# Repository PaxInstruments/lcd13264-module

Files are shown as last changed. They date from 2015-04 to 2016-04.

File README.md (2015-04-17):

# Pax Instruments
# LCD13264-module

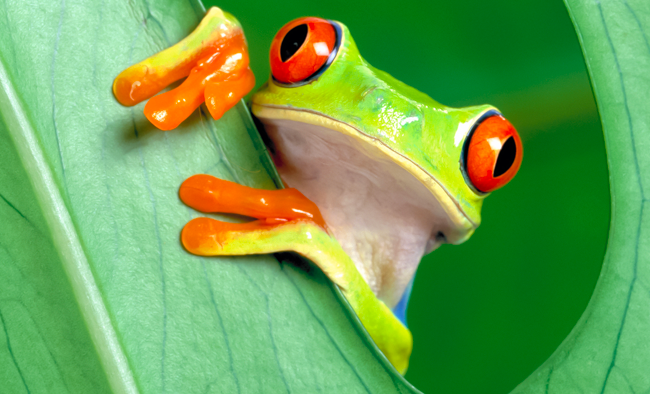
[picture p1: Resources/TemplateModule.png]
  
[Pax Instruments Template Module](<link to store page>)

## Overview
The Pax Instruments LCD13264-module is a breakout shield for the LCD23164 graphic LCD.

## Repository Contents
- __Datasheets__ - Datasheets for relevant components and parts
- __Electronics__ - All PCB and schematic design files
- __Enclosure__ - Enclosure 3D design files
- __Firmware__ - Firmware, libraries, and examples
- __Production__ - Manufacturing resources
- __Resources__ - Other resources

## Product Versions

## License Information
```
Place the license statement here
```

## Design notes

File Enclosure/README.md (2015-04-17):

# Pax Instruments
# LCD12364-shield Enclosure

Developed by <person(s) name> for [Pax Instruments](http://paxinstruments.com/), an original design.

## Overview
This is the enclsoure for the Pax Instruments LCD13264-module designed in <software package>. STL files are included for your convenience.

## License
```
Place the license statement here
```

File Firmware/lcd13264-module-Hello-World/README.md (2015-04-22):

# Pax Instruments
# LCD12364-shield Firmware

Developed by <person(s) name> for [Pax Instruments](http://paxinstruments.com/) based on Arduino and other Open Source libraries.

## Overview
There is no firmware required for the Pax Instruments LCD12364-shield.

## Required libraries
- Link to a forked Pax Instruments version
- of any  libraries used

## Installation
1. Copy libraryName into your <Arduino folder>/libraries/
2. Restart the ARduino IDE

## Example 1 - Hello, world!
```
void setup() {
    // The setup function. This runs once.
}

void loop() {
    // The loop function. This restarts when complete.
}
```

## History
__v0.2: 2015-02-22 by Charles Edward Pax__

- Major change 1
- Major change 2

__v0.1: 2015-02-20 by Charles Edward Pax__

- Major change 1
- Major change 2

## License
```
Place the license statement here
```

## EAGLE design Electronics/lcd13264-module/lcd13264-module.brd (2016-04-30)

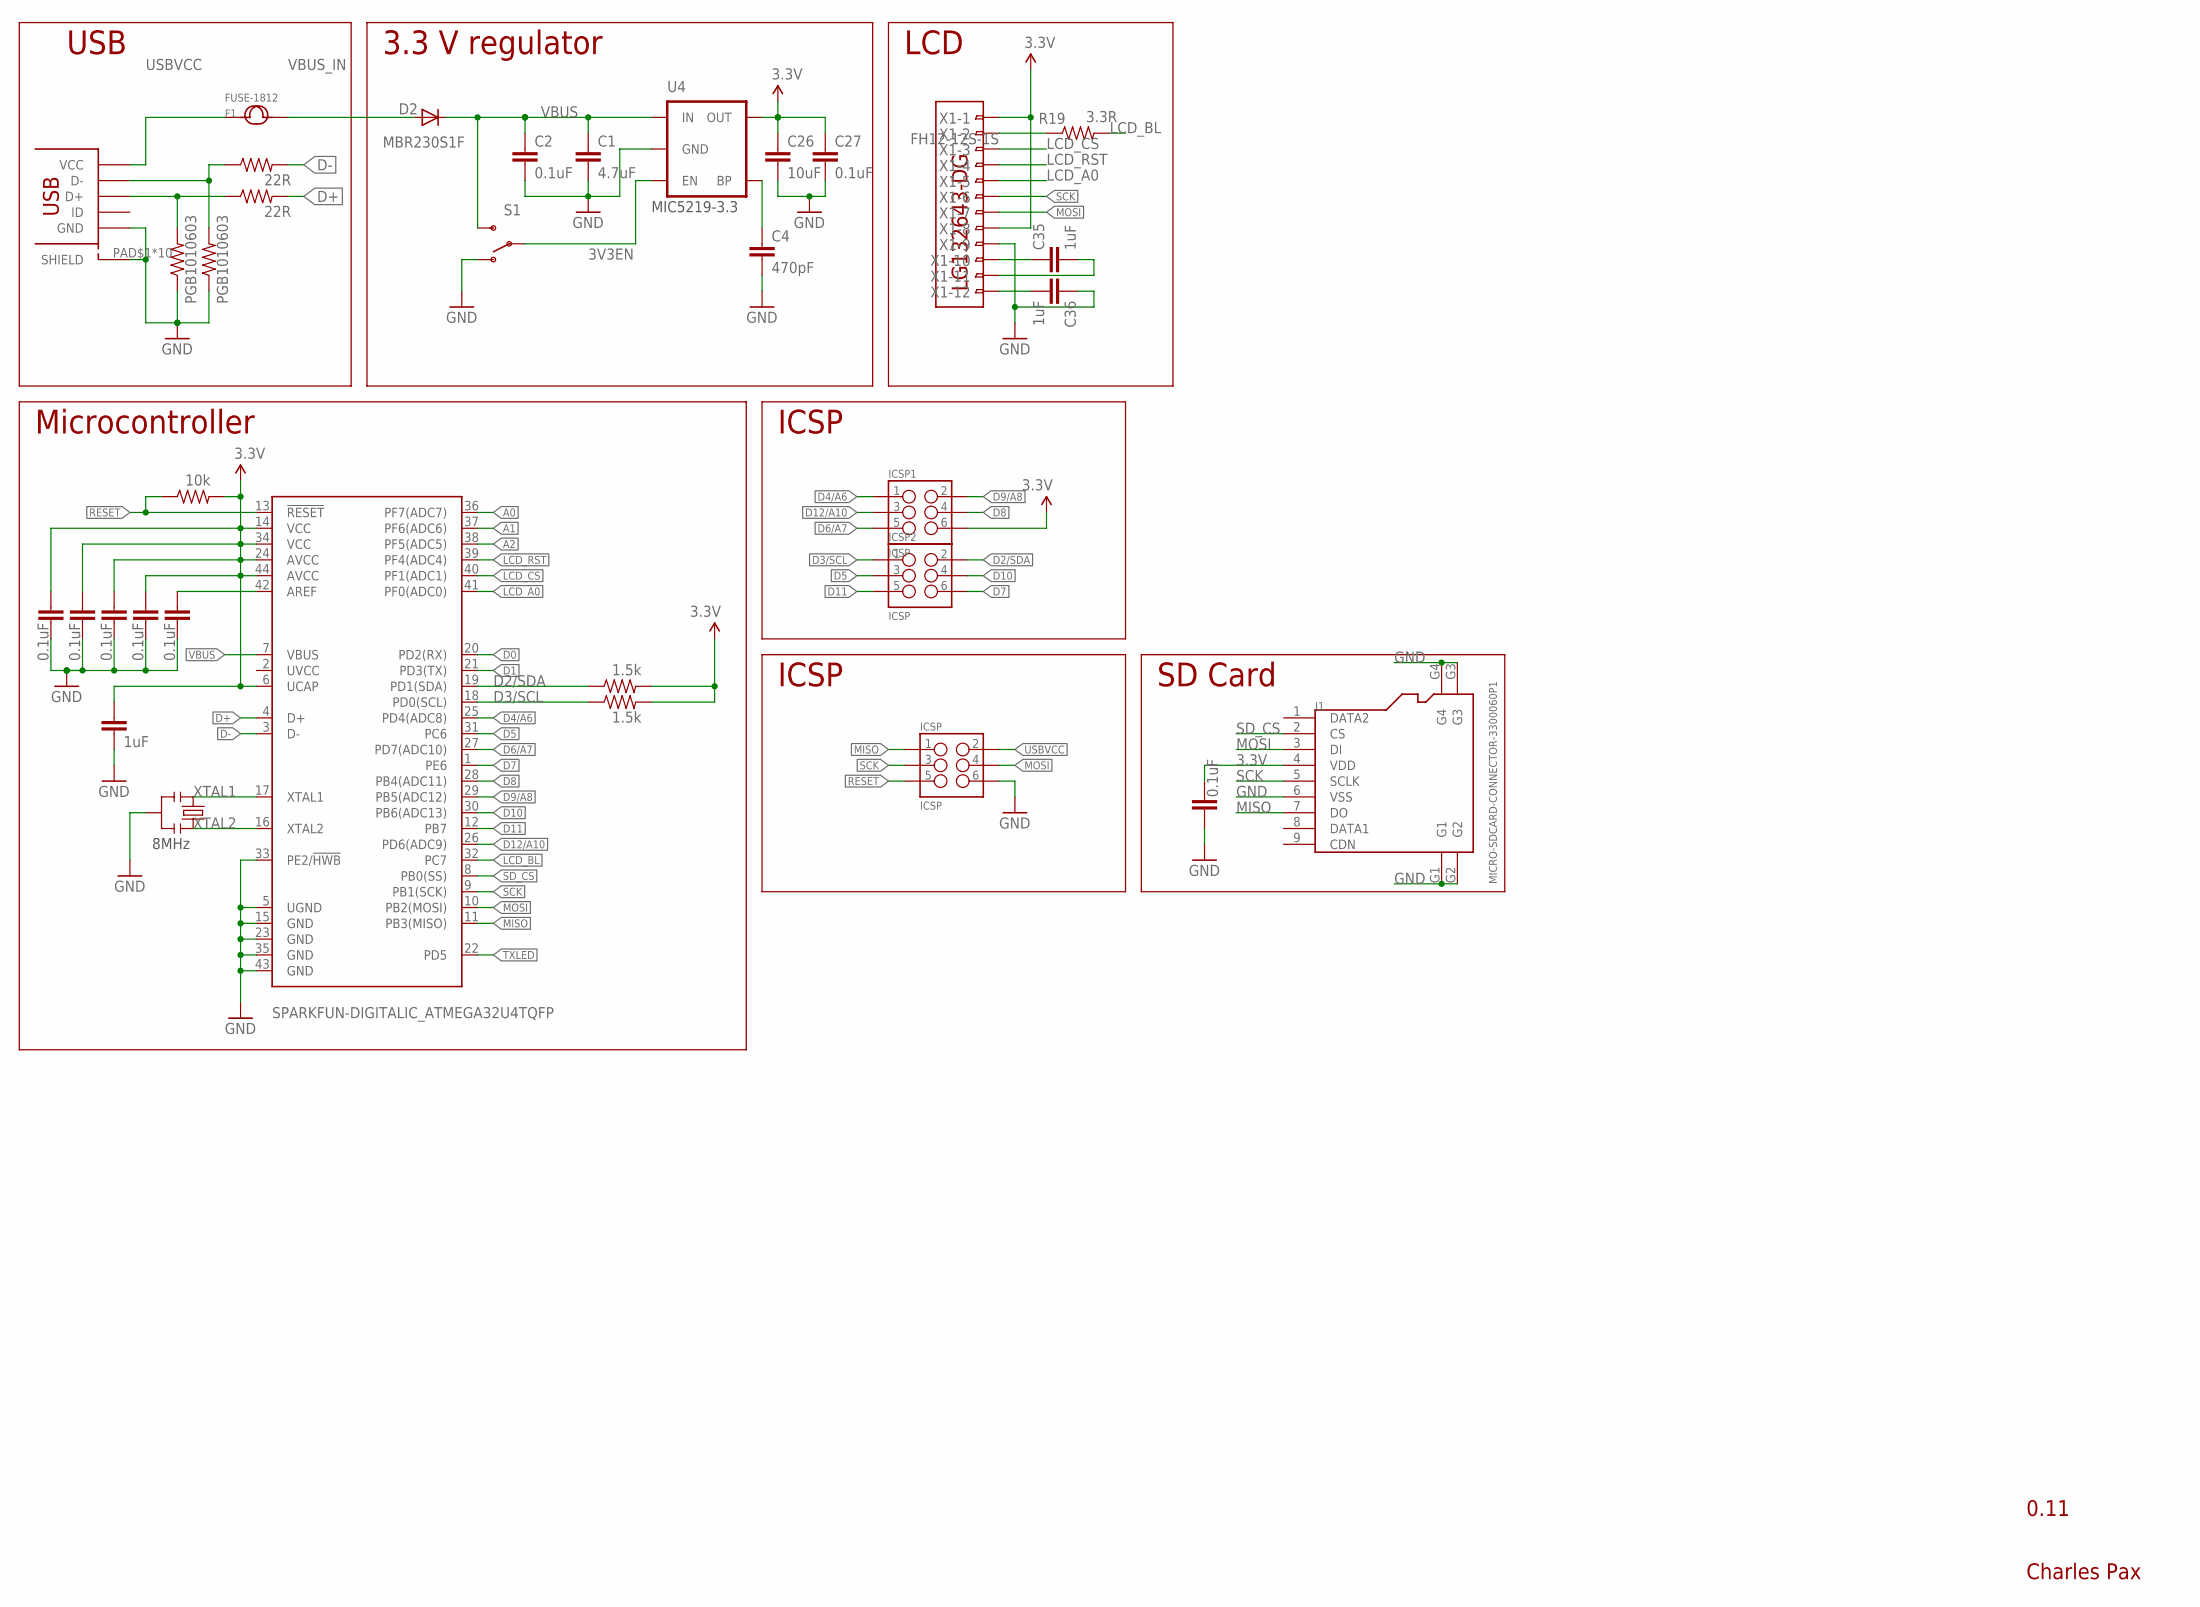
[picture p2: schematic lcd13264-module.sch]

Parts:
C1: 4.7uF; SPARKFUN-CAPACITORS_0603-CAP; MPN GRM188R60J475KE19D
C2, C3, C5, C21, C27, C32, C33, C34: 0.1uF; SPARKFUN-CAPACITORS_0603-CAP; MPN CL10B104KO8NNNC
C4: 470pF; SPARKFUN-CAPACITORS_0603-CAP; MPN C1608X5R1A474K080AA
C19, C35, C36: 1uF; SPARKFUN-CAPACITORS_0603-CAP; MPN LMK107B7105KA-T
C26: 10uF; SPARKFUN-CAPACITORS_0603-CAP; MPN JMK107ABJ106MAHT
D2: MBR230S1F; SOD123; MPN B340A-13-F
F1: FUSE-1812; F1812
ICSP, ICSP1, ICSP2: ICSP; SPARKFUN-CONNECTORS_2X3_SMT_POSTS_PAXINSTRUMENT; MPN 95278-101A06LF
J1: MICRO-SDCARD-CONNECTOR-3300060P1; 9P-SMD-W-RING
R4: 10k; SPARKFUN-RESISTORS_0603-RES; MPN RC1608J103CS
R9, R10: 22R; SPARKFUN-RESISTORS_0603-RES; MPN RC0603JR-0722RL
R13, R14: 1.5k; SPARKFUN-RESISTORS_0603-RES; MPN RC0603JR-071K5L
R19: 3.3R; SPARKFUN-RESISTORS_0603-RES
S1: SWITCH-SPDT-SMD-A; SWITCH-SPST-SMD-A
U4: MIC5219-3.3V; SOT23-5; MPN MIC5219-3.3YM5 TR
U$1: USB_MICROSMT+THRUHULE; USB_MICRO_THRUHOLE; MPN 10118194-0001LF
U$3: SPARKFUN-DIGITALIC_ATMEGA32U4TQFP; SPARKFUN-DIGITALIC_SPARKFUN-DIGITALIC_TQFP44
U$5: LG132643-DG; MPN LG132643-DW
X1: FH12-12S-1S; FH12-12S-1SH
Y1: RESONATORSMD; RESONATOR-SMD; MPN CSTCE8M00G52-R0
Z1, Z2: PGB1010603; SPARKFUN-RESISTORS_0603-RES; MPN PGB1010603NRHF

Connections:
3.3V: C5.1, C19.1, C21.2, C26.1, C27.1, C32.1, C33.1, C34.1, ICSP1.6, J1.4 (VDD), R4.2, R13.2, R14.2, U4.5 (OUT), U$3.6 (UCAP), U$3.14 (VCC), U$3.24 (AVCC), U$3.34 (VCC), U$3.44 (AVCC), X1.1, X1.8
3V3EN: S1.2, U4.3 (EN)
A0: U$3.36 (PF7(ADC7))
A1: U$3.37 (PF6(ADC6))
A2: U$3.38 (PF5(ADC5))
D0: U$3.20 (PD2(RX))
D1: U$3.21 (PD3(TX))
D2/SDA: ICSP2.2, R13.1, U$3.19 (PD1(SDA))
D3/SCL: ICSP2.1, R14.1, U$3.18 (PD0(SCL))
D4/A6: ICSP1.1, U$3.25 (PD4(ADC8))
D5: ICSP2.3, U$3.31 (PC6)
D6/A7: ICSP1.5, U$3.27 (PD7(ADC10))
D7: ICSP2.6, U$3.1 (PE6)
D8: ICSP1.4, U$3.28 (PB4(ADC11))
D9/A8: ICSP1.2, U$3.29 (PB5(ADC12))
D10: ICSP2.4, U$3.30 (PB6(ADC13))
D11: ICSP2.5, U$3.12 (PB7)
D12/A10: ICSP1.3, U$3.26 (PD6(ADC9))
D+: R9.2, U$3.4 (D+)
D-: R10.2, U$3.3 (D-)
GND: C1.2, C2.2, C3.2, C4.2, C5.2, C19.2, C21.1, C26.2, C27.2, C32.2, C33.2, C34.2, C36.1, ICSP.6, J1.6 (VSS), J1.G1, J1.G2, J1.G3, J1.G4, S1.1 (O), U4.2 (GND), U$1.PAD$1 (SHIELD), U$1.PAD$2 (SHIELD), U$1.PAD$3 (SHIELD), U$1.PAD$4 (SHIELD), U$1.PAD$5 (SHIELD), U$1.PAD$6 (SHIELD), U$1.PAD$7 (SHIELD), U$1.PAD$8 (SHIELD), U$1.PAD$9 (SHIELD), U$1.PAD$10 (SHIELD), U$1.PIN$5 (GND), U$3.5 (UGND), U$3.15 (GND), U$3.23 (GND), U$3.33 (PE2/!HWB), U$3.35 (GND), U$3.43 (GND), X1.9, Y1.2, Z1.1, Z2.1
LCD_A0: U$3.41 (PF0(ADC0)), X1.5
LCD_BL: R19.2, U$3.32 (PC7)
LCD_CS: U$3.40 (PF1(ADC1)), X1.3
LCD_RST: U$3.39 (PF4(ADC4)), X1.4
MISO: ICSP.1, J1.7 (DO), U$3.11 (PB3(MISO))
MOSI: ICSP.4, J1.3 (DI), U$3.10 (PB2(MOSI)), X1.7
unnamed: C4.1, U4.4 (BP)
unnamed: R19.1, X1.2
unnamed: C35.1, X1.10
unnamed: C36.2, X1.12
unnamed: C3.1, U$3.42 (AREF)
unnamed: R10.1, U$1.PIN$2 (D-), Z2.2
unnamed: R9.1, U$1.PIN$3 (D+), Z1.2
unnamed: C35.2, X1.11
RESET: ICSP.5, R4.1, U$3.13 (!RESET)
SCK: ICSP.3, J1.5 (SCLK), U$3.9 (PB1(SCK)), X1.6
SD_CS: J1.2 (CS), U$3.8 (PB0(SS))
TXLED: U$3.22 (PD5)
USBVCC: F1.1, ICSP.2, U$1.PIN$1 (VCC)
VBUS: C1.1, C2.1, D2.C, S1.3 (S), U4.1 (IN), U$3.7 (VBUS)
VBUS_IN: D2.A, F1.2
XTAL1: U$3.17 (XTAL1), Y1.1
XTAL2: U$3.16 (XTAL2), Y1.3

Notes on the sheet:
MIC5219-3.3
8MHz
USB
3.3 V regulator
LCD
Microcontroller
ICSP
0.11
Charles Pax
SD Card

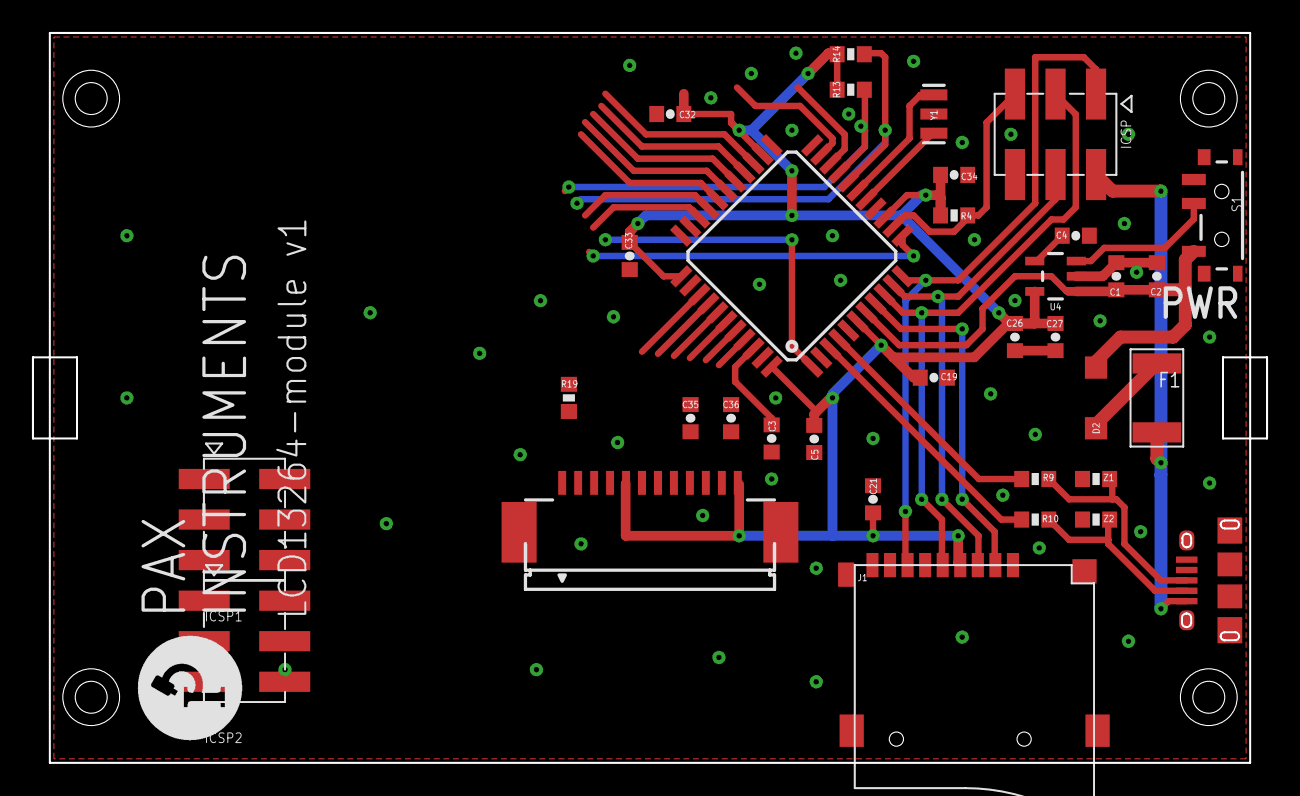
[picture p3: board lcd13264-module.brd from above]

Board: 2 copper layers, 77.3 x 45.7 mm, 36 parts (0 on the bottom side), 38 nets.

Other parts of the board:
U$6: PAXINSTRUMENT_LOGO

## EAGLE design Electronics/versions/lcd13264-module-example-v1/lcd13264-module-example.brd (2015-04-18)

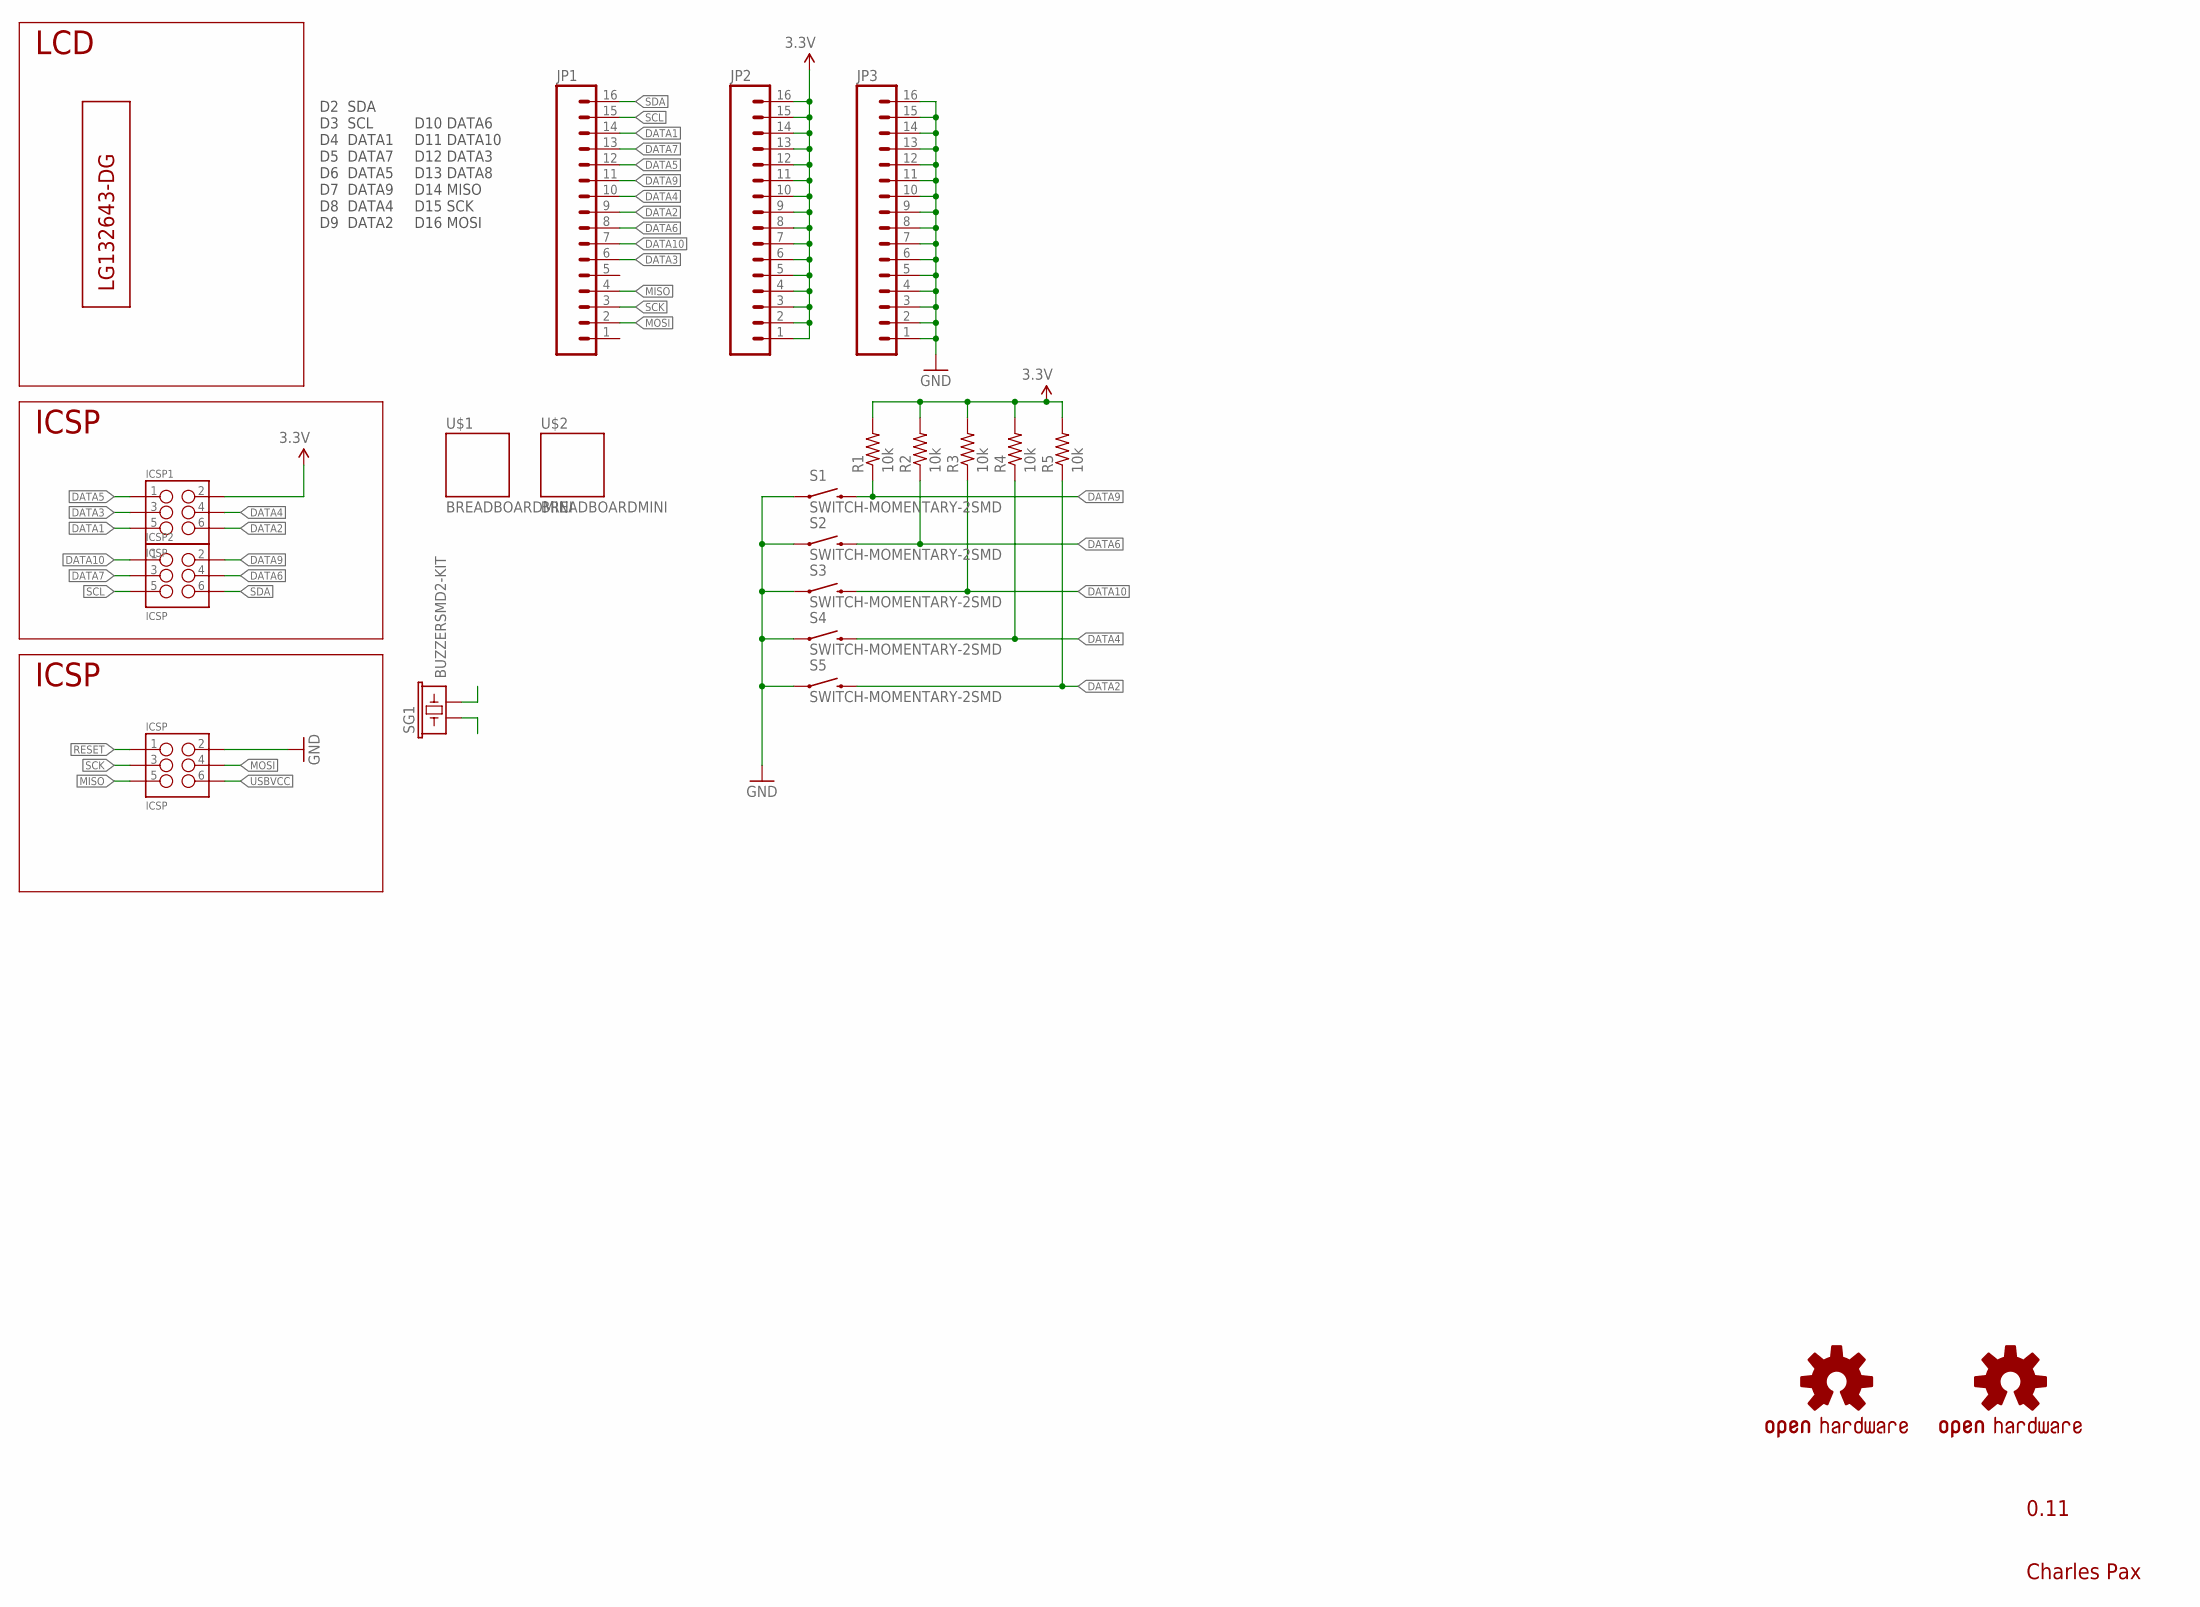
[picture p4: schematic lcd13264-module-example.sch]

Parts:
ICSP, ICSP1, ICSP2: ICSP; SPARKFUN-CONNECTORS_2X3_SMT_POSTS_PAXINSTRUMENT; MPN 95278-101A06LF
JP1, JP2, JP3: M161X16_NO_SILK; 1X16_NO_SILK
LOGO1: OSHW-LOGOL; OSHW-LOGO-L
LOGO2: OSHW-LOGOL-COPPER; OSHW-LOGO-L_COPPER
R1, R2, R3, R4, R5: 10k; 0603-RES
S1, S2, S3, S4, S5: SWITCH-MOMENTARY-2SMD; TACTILE-SWITCH-SMD
SG1: BUZZERSMD2-KIT; BUZZER-CCV-KIT
U$1, U$2: BREADBOARDMINI; BREADBOARD-MINI
U$5: LG132643-DG; MPN LG132643-DW

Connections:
3.3V: ICSP1.2, JP2.1, JP2.2, JP2.3, JP2.4, JP2.5, JP2.6, JP2.7, JP2.8, JP2.9, JP2.10, JP2.11, JP2.12, JP2.13, JP2.14, JP2.15, JP2.16, R1.2, R2.2, R3.2, R4.2, R5.2
DATA1: ICSP1.5, JP1.14
DATA2: ICSP1.6, JP1.9, R5.1, S5.3 (2)
DATA3: ICSP1.3, JP1.6
DATA4: ICSP1.4, JP1.10, R4.1, S4.3 (2)
DATA5: ICSP1.1, JP1.12
DATA6: ICSP2.4, JP1.8, R2.1, S2.3 (2)
DATA7: ICSP2.3, JP1.13
DATA9: ICSP2.2, JP1.11, R1.1, S1.3 (2)
DATA10: ICSP2.1, JP1.7, R3.1, S3.3 (2)
GND: ICSP.2, JP3.1, JP3.2, JP3.3, JP3.4, JP3.5, JP3.6, JP3.7, JP3.8, JP3.9, JP3.10, JP3.11, JP3.12, JP3.13, JP3.14, JP3.15, JP3.16, S1.1, S2.1, S3.1, S4.1, S5.1
MISO: ICSP.5, JP1.4
MOSI: ICSP.4, JP1.2
RESET: ICSP.1
SCK: ICSP.3, JP1.3
SCL: ICSP2.5, JP1.15
SDA: ICSP2.6, JP1.16
USBVCC: ICSP.6

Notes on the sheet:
LCD
ICSP
0.11
Charles Pax
D2 SDA D3 SCL D4 DATA1 D5 DATA7 D6 DATA5 D7 DATA9 D8 DATA4 D9 DATA2
D10 DATA6 D11 DATA10 D12 DATA3 D13 DATA8 D14 MISO D15 SCK D16 MOSI

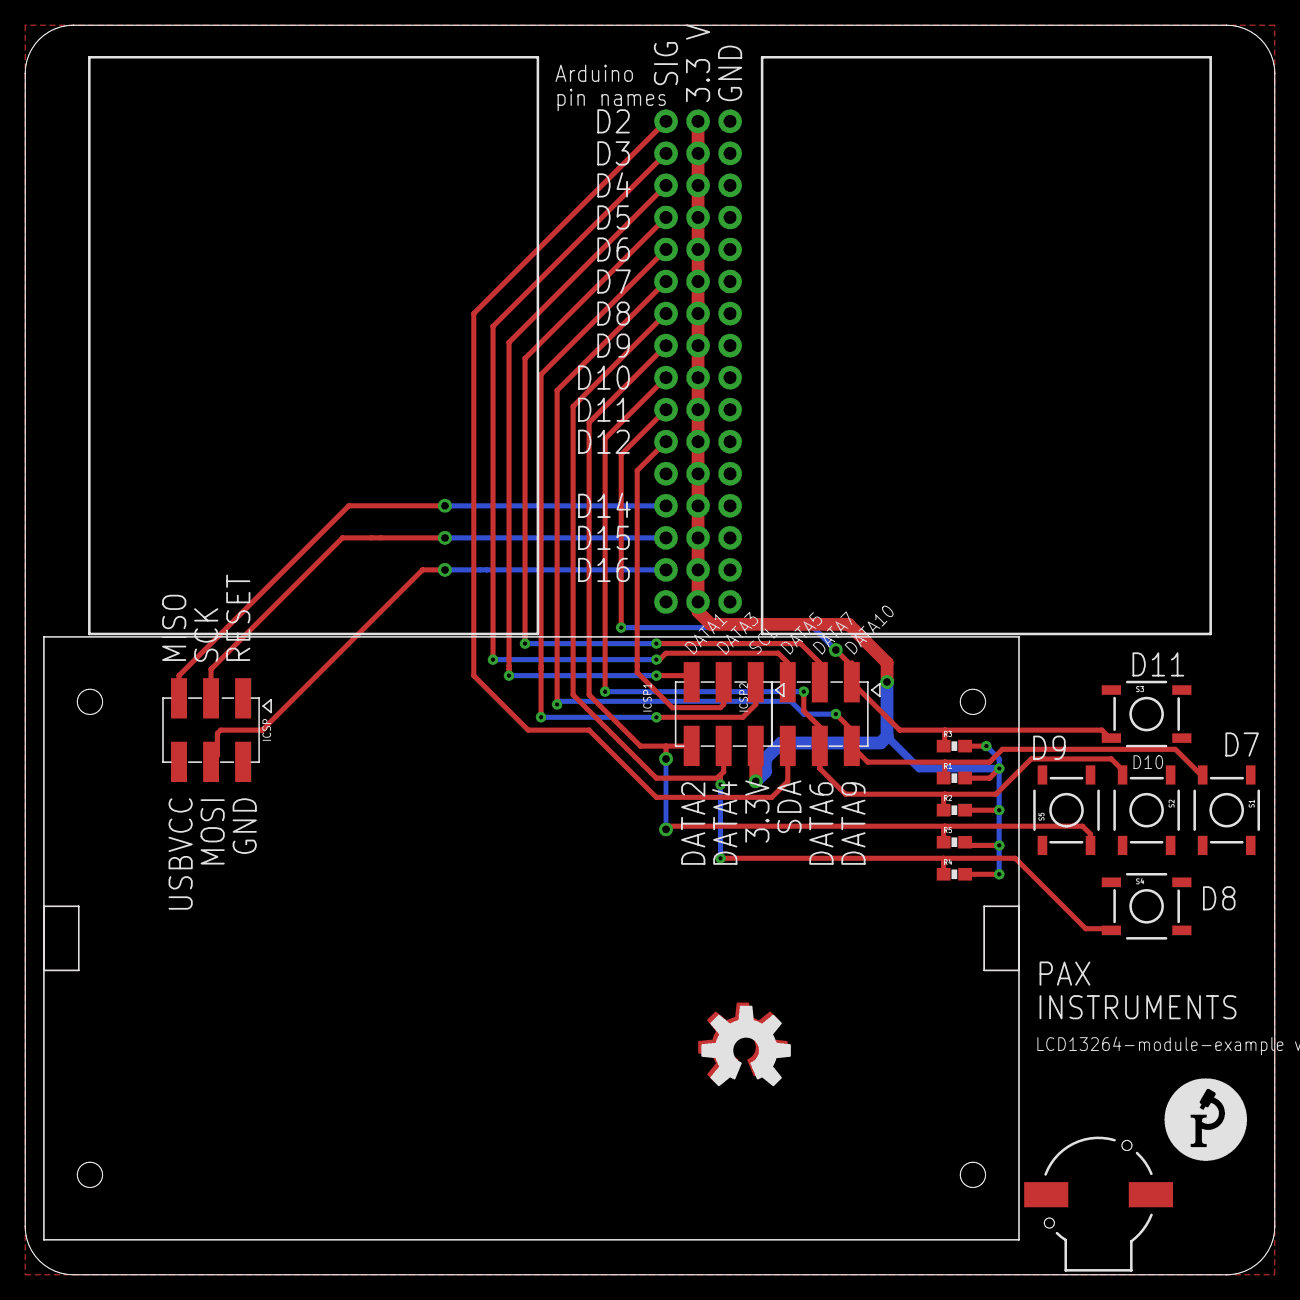
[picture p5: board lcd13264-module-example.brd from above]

Board: 2 copper layers, 99.1 x 99.1 mm, 23 parts (1 on the bottom side), 16 nets.

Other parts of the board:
U$6: PAXINSTRUMENT_LOGO

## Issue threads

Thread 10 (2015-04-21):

Spring strength

charlespax, 2015-04-21:
Make sure the spring strength is small. The LCD clips are not the strongest.

charlespax, 2015-04-26:
In the first test I had three 2x3 headers, which was simply too strong. The LCD and PCB were bending a little.

I think we should use a connector that isn't fighting against the LCD clips.

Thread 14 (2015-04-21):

LCD pin order

charlespax, 2015-04-21:
The LCD pins appear to be in reverse order and as such the LCD must be connected backwards. Let's fix this.

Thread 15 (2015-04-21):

LCd connector type

charlespax, 2015-04-21:
It would be nice to have a flip top connector. I think we're using one in the T400.

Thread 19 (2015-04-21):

Buzzer location

charlespax, 2015-04-21:
We can put the buzzer under the LCD and get some more on the right side of the PCB.

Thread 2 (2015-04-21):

Connector footprints

charlespax, 2015-04-21:
Make sure the connector footprint matches the connector for both the spring contact and the SMD connection.

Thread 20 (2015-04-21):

Header color

charlespax, 2015-04-21:
Black looks fine, but maybe white headers would be cooler. Maybe use black for GND, red for 3V3, and white for SIG. Are the colors on servo cables standard?

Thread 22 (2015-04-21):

Extra goodies

charlespax, 2015-04-21:
We should put some additional I/O goodies on the example board. Just toss some simple cheap ones on there.

- Light sensor
- Fun LEDs to blink
- Thermistor
- Vibration motor

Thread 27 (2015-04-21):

Example board extra headers

charlespax, 2015-04-21:
We could have an extra row of signal headers, so a user can connect two things directly to the breakout header. This would make the breakout headers incompatible with servo connectors though.

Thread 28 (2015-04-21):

Example board extra power rail headers

charlespax, 2015-04-21:
It would be cool to have extra power and ground headers along the outside of the breadboards. This is better than getting wider breadboards.

charlespax, 2015-04-21:
See also https://github.com/PaxInstruments/lcd13264-module/issues/27

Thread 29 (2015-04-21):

Example board pin labels

charlespax, 2015-04-21:
Some parts on the example board are labeled wit their net names (e.g. DATA1). This is bad as things get confused with the Arduino digital pins. We should change the labels to reflect the Arduino pin names.

We should also change the names of the nets in the design files. Things should be consistent.

charlespax, 2015-04-22:
We should label the bottom too.

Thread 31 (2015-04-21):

LCD tab breakage

charlespax, 2015-04-21:
The Tabs on the LCD can break. Maybe decrease the width of the tab slot to prevent the tab from being flexed to far.

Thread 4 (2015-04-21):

Spring loaded contacts

charlespax, 2015-04-21:
We need to find good spring loaded contacts. We must be careful to account for the PCB thickness (https://github.com/PaxInstruments/lcd13264-module/issues/3).

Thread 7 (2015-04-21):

PCB press fit

charlespax, 2015-04-21:
We can probably make the PCB press fit onto the LCD by splitting the holes that go around the standoffs and making them a little smaller.

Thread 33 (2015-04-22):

Example board mounting holes

charlespax, 2015-04-22:
We should probably have some kind of mounting holes in case some wants to screw their board to something.

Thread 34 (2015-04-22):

Example board breakout boards

charlespax, 2015-04-22:
There is plenty of empty space on the example board. It would be cool to drop in a bunch of breakout boards for various things.

We can have traces go to the boards, so they can be used directly on the example board. They can also be snapped out and used in the breadboard.

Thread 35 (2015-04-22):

Example board 5-way switch

charlespax, 2015-04-22:
We have five discrete buttons on the example board. Maybe it would be better to have a 5-way switch.

I think discrete switches more clearly indicates what is happening; one digital pin for each switch. Five lines to one device could be confusing for beginners.

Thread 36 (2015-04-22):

SD card slot location

charlespax, 2015-04-22:
It may be good to have the microSD card slot within the boarder of the LCD. We should see how it fits in the T400 enclosure.

charlespax, 2015-04-22:
It would be good to put the microSD card slot on the same side as it would be in the enclosure. This would make the breakout pins very easy to route. Otherwise, the traces would have to be routed across the PCB. Just make sure the heights of two slots do not interfere.

charlespax, 2015-04-22:
If we move it in just a hair, we would be clear of the enclosure when a card is installed. Right now an installed SD card just slightly touches the inside of the enclosure.

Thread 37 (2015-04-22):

Connector locations

charlespax, 2015-04-22:
Do not put the spring loaded connectors along the top. If the LCD module is used in the enclosure we would want the top area clear for whatever the user puts at the top to interface with the outside world. There may be daughter board connectors that interface through the top panel.

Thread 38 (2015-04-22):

Example board reverse prototyping

charlespax, 2015-04-22:
It would be cool if people can prototype on the back side of the PCB. Then they can mount the PCB on an enclosure and have a nice interface with their custom stuff.

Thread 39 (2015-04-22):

Oscillator chip size

charlespax, 2015-04-22:
The oscillator must be large enough for a person to easily hand solder. We should more to a larger component and appropriately modify the footprint for hand soldering.

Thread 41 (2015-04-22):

Example board buttons

charlespax, 2015-04-22:
Each button is connected to one Arduino pin. Maybe we should change this to an analog read on a single analog pin. This is commonly used in Arduino character LCD shields.
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

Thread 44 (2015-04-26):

Mezzanine connectors

charlespax, 2015-04-26:
Spring contacts may not work if they are to strong (https://github.com/PaxInstruments/lcd13264-module/issues/10). Using Mezzanine connectors could be a better solution. They would work with the LCD clips and may even hold the LCD in place if there clips were to break.

The down side here is the user would have to solder a mating connector to their PCB rather than just having a footprint on their board.

See http://www.digikey.com/product-search/en/connectors-interconnects/rectangular-board-to-board-connectors-arrays-edge-type-mezzanine/1442154

charlespax, 2015-04-27:
Here is a table listing the possible nominal mating heights for mezzanine connectors.

LCD | PCB | Mez
---|---|---
4.7 | 0.6 | 4.1
4.7 | 0.8 | 3.9
4.7 | 1.0 | 3.7
4.7 | 1.2 | 3.5
4.7 | 1.6 | 3.1
4.7 | 2.0 | 2.7

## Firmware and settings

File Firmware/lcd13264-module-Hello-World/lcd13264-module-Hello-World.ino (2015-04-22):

/*

  HelloWorld.pde
  
  "Hello World!" example code.
  
  >>> Before compiling: Please remove comment from the constructor of the 
  >>> connected graphics display (see below).
  
  Universal 8bit Graphics Library, http://code.google.com/p/u8glib/
  
  Copyright (c) 2012, olikraus@gmail.com
  All rights reserved.

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
  THIS SOFTWARE IS PROVIDED BY THE COPYRIGHT HOLDERS AND 
  CONTRIBUTORS "AS IS" AND ANY EXPRESS OR IMPLIED WARRANTIES, 
  INCLUDING, BUT NOT LIMITED TO, THE IMPLIED WARRANTIES OF 
  MERCHANTABILITY AND FITNESS FOR A PARTICULAR PURPOSE ARE 
  DISCLAIMED. IN NO EVENT SHALL THE COPYRIGHT HOLDER OR 
  CONTRIBUTORS BE LIABLE FOR ANY DIRECT, INDIRECT, INCIDENTAL, 
  SPECIAL, EXEMPLARY, OR CONSEQUENTIAL DAMAGES (INCLUDING, BUT 
  NOT LIMITED TO, PROCUREMENT OF SUBSTITUTE GOODS OR SERVICES; 
  LOSS OF USE, DATA, OR PROFITS; OR BUSINESS INTERRUPTION) HOWEVER 
  CAUSED AND ON ANY THEORY OF LIABILITY, WHETHER IN CONTRACT, 
  STRICT LIABILITY, OR TORT (INCLUDING NEGLIGENCE OR OTHERWISE) 
  ARISING IN ANY WAY OUT OF THE USE OF THIS SOFTWARE, EVEN IF 
  ADVISED OF THE POSSIBILITY OF SUCH DAMAGE.  
  
*/

// This documen is modified to work with the Pax Instruments LCD Test Board v0.2
#define LCD_MOSI             A0
#define LCD_SCK              A1
#define LCD_A0               A2
#define LCD_RST              A3
#define LCD_CS               A4
#define LCD_BACKLIGHT_PIN    A5    // LCD backlight on pin
// MISO                     14
// SCK                      15
// MOSI                     16
#define SW_A_pin             11
#define SW_B_pin             9
#define SW_C_pin             10
#define SW_D_pin             7
#define SW_E_pin             8
#define SD_CS                17

#define LCD_CONTRAST     0x018*7  // Sets the LCD contrast

#include "U8glib.h"
#include <SdFat.h>

// U8GLIB_PI13264  u8g(LCD_CS, LCD_A0, LCD_RST); // Use HW-SPI
 U8GLIB_PI13264  u8g(LCD_SCK, LCD_MOSI, LCD_CS, LCD_A0, LCD_RST); // Use SW-SPI

SdFat sd;
SdFile myFile;
int sd_test_status = 0;

int SW_A_state = 0;
int SW_B_state = 0;
int SW_C_state = 0;
int SW_D_state = 0;
int SW_E_state = 0;

int fadeValue = 0;
int updown = 1; // is the fading going up or down

int sdTest(){
//  Serial.begin(9600);
//  while (!Serial) {}  // wait for Leonardo
//  Serial.println("Type any character to start");
//  while (Serial.read() <= 0) {}
//  delay(400);  // catch Due reset problem
 // if (sd.begin(SD_CS, SPI_HALF_SPEED)) sd.initErrorHalt();
  sd.begin(SD_CS, SPI_HALF_SPEED);
  if (!myFile.open("test.txt", O_RDWR | O_CREAT | O_AT_END)) {
    //sd.errorHalt("opening test.txt for write failed");
    return 0;
  }
//  Serial.print("Writing to test.txt...");
  myFile.println("testing 1, 2, 3.");
  myFile.close();
//  Serial.println("done.");
  if (!myFile.open("test.txt", O_READ)) {
   // sd.errorHalt("opening test.txt for read failed");
    return 0;
  }
//  Serial.println("test.txt:");
  int data;
  while ((data = myFile.read()) >= 0) Serial.write(data);
  // close the file:
  myFile.close();
  return 1;
}

void draw(void) {
  // graphic commands to redraw the complete screen should be placed here  
  //u8g.setFont(u8g_font_unifont);
  u8g.setFont(u8g_font_ncenR12);
  u8g.drawStr( 0, 14, "PAX");
  u8g.drawStr( 0, 30, "INSTRUMENTS");
  
  u8g.setFont(u8g_font_5x8);
  u8g.drawStr( 0, 39, "OPENSOURCE LAB INSTRUMENTS");
  u8g.drawStr( 0, 62, "Graphic LCD 132x64 shield");
  
  // Draw button stuff
  if (SW_A_state == LOW) {     
    u8g.drawStr( 0, 50, "A");
  } 
  if (SW_B_state == LOW) {     
    u8g.drawStr( 5, 50, "B");
  } 
  if (SW_C_state == LOW) {     
    u8g.drawStr( 10, 50, "C");
  } 
  if (SW_D_state == LOW) {     
    u8g.drawStr( 15, 50, "D");
    if (SW_C_state == LOW){
      if (sd_test_status == 0){
        u8g.drawStr( 75, 50, "SD: bad");
      }
      if (sd_test_status == 1){
        u8g.drawStr( 75, 50, "SD: okay");
      }
    }
  } 
  if (SW_E_state == LOW) {     
    u8g.drawStr( 20, 50, "E  Fading...");
  } 
}

void setup(void) {
  sd_test_status = sdTest();
    // flip screen, if required
  u8g.setRot180();
  u8g.setContrast(LCD_CONTRAST);
  
  pinMode(LCD_BACKLIGHT_PIN, OUTPUT);           
  analogWrite(LCD_BACKLIGHT_PIN, fadeValue);   

  // assign default color value
  if ( u8g.getMode() == U8G_MODE_R3G3B2 ) {
    u8g.setColorIndex(255);     // white
  }
  else if ( u8g.getMode() == U8G_MODE_GRAY2BIT ) {
    u8g.setColorIndex(3);         // max intensity
  }
  else if ( u8g.getMode() == U8G_MODE_BW ) {
    u8g.setColorIndex(1);         // pixel on
  }
  else if ( u8g.getMode() == U8G_MODE_HICOLOR ) {
    u8g.setHiColorByRGB(255,255,255);
  }
  
  // Set up the buttons
    pinMode(SW_A_pin, INPUT);
    pinMode(SW_B_pin, INPUT);
    pinMode(SW_C_pin, INPUT);
    pinMode(SW_D_pin, INPUT);
    pinMode(SW_E_pin, INPUT);
}



void loop(void) {
  SW_A_state = digitalRead(SW_A_pin);
  SW_B_state = digitalRead(SW_B_pin);
  SW_C_state = digitalRead(SW_C_pin);
  SW_D_state = digitalRead(SW_D_pin);
  SW_E_state = digitalRead(SW_E_pin);
  
  // picture loop
  u8g.firstPage();  
  do {
    draw();
  } while( u8g.nextPage() );
  // rebuild the picture after some delay
  delay(50);
  
  // fade in from min to max in increments of 5 points:

  while(SW_E_state == false){
    if (fadeValue >=255){
      updown = 0;
    }
    if (fadeValue <= 0 ){
      updown = 1;
    }
    
    analogWrite(LCD_BACKLIGHT_PIN, fadeValue);         
    delay(10);
    if (updown == true){
      fadeValue +=5;
    }
    if (updown == false){
      fadeValue -=5;
    }
    SW_E_state = digitalRead(SW_E_pin);
  }
  if (SW_D_state == false){
   sd_test_status = sdTest(); 
  }
}

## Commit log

2015-04-17 Added PCD design. Just need to breakout some data pins now.
    [lcd13264-module.brd, lcd13264-module.sch]
2015-04-18 Finished layout of v1. Copied design to v1 folder. Sending to board house.
    [lcd13264-module.brd, lcd13264-module.sch]
2015-04-18 Added a template daughter board outline 10 x 10 cm.\n- verified the pins match between the two boards.
    [lcd13264-module-template.brd, lcd13264-module-template.sch]
2015-04-18 Added an example board using the LCD module template. Just headers, a buzzer, breadboards, and buttons.
    [lcd13264-module-example.brd, lcd13264-module-example.sch]
2015-04-18 Sending module example to board house. Added a module example versions volder.
    [lcd13264-module-example.brd, lcd13264-module-example.sch]
2015-04-18 Updated LCD connector.
    [lcd13264-module.brd, lcd13264-module.sch]
2016-04-30 Unknown changes.
    [lcd13264-module.brd, lcd13264-module.sch]

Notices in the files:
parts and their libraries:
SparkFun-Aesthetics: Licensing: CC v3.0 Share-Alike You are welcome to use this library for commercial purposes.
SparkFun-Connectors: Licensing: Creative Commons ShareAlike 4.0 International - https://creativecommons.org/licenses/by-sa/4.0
